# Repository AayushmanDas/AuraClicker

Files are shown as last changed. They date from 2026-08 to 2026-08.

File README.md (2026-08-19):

# ⚡ AuraClicker

A compact, battery-powered custom macro-pad and wireless input controller powered by the **ESP32-C3** RISC-V microcontroller. 

Designed natively in **KiCad** with end-to-end Design for Manufacturing (DFM) verification, ready for turnkey fabrication and assembly via JLCPCB SMT services.

---

## 📸 Media & Previews

| 3D PCB Preview | JLCPCB DFM Placement |
| :---: | :---: |
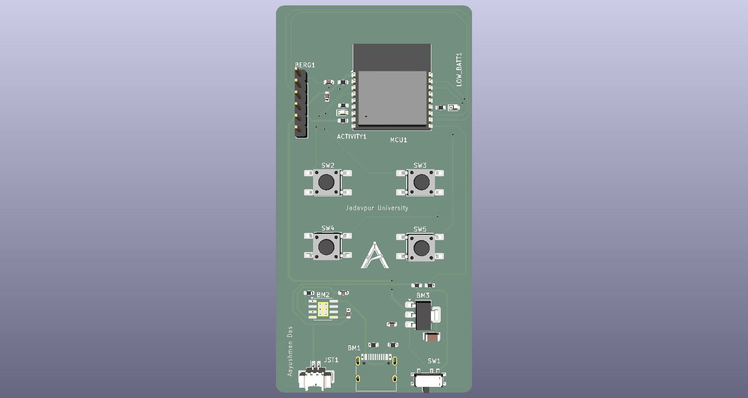
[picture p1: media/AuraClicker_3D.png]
3D Render
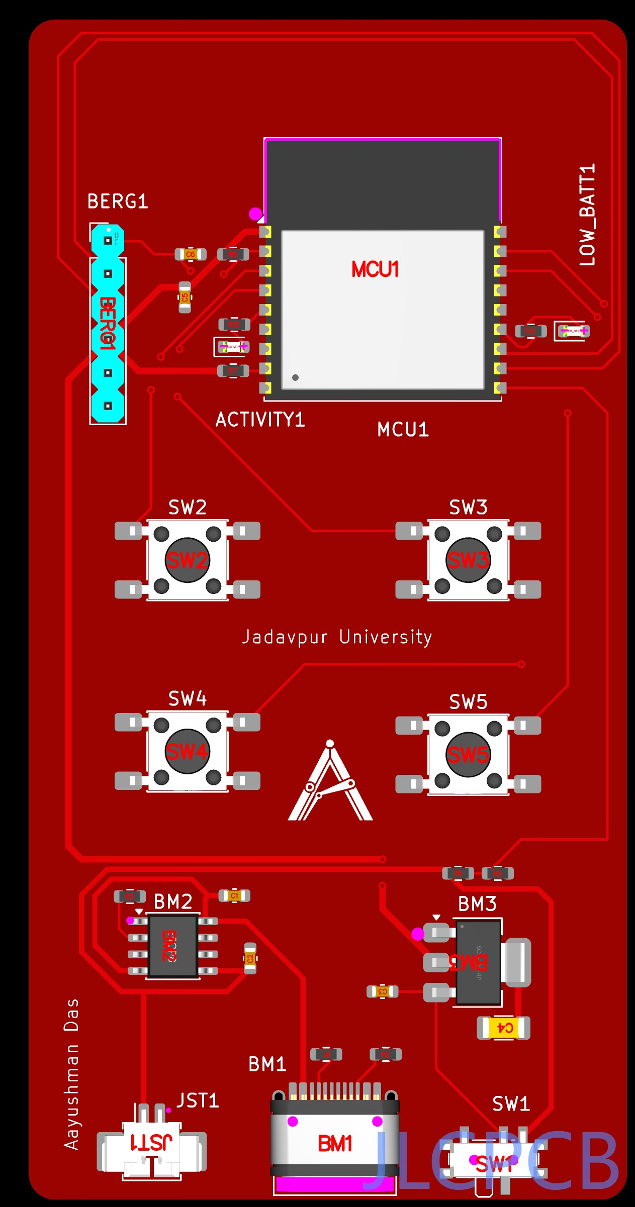
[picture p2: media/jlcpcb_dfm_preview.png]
DFM Preview
|  |  |

---

## ✨ Key Features

* **MCU Core:** ESP32-C3 RISC-V SoC (2.4 GHz Wi-Fi & Bluetooth 5 LE).
* **Power & Battery Management:**
  * Dedicated **TP4056** Li-Po linear charging IC over USB-C.
  * **AMS1117-3.3** high-current LDO for clean 3.3V power distribution.
  * 2-Pin **Molex PicoBlade (1.25mm)** battery connector. Recommended to be used with 3.7-4.2V 500mAh LiPo battery.
  * Hardware SPDT power slide switch (`SW1`).
* **Inputs & Peripherals:**
  * 4x Low-profile tactile click buttons (`SW2` – `SW5`) arranged for ergonomic thumb/finger reach.
  * Status LEDs for battery activity and low-power telemetry.
* **Programming & Debugging:**
  * Standard 1x6 (2.54mm) FTDI / UART header (`BERG1`) for serial programming and debug monitoring.

---

## 🗂️ Repository Structure

```text
AuraClicker/
├── kicad/                        # Raw KiCad project and PCB design files
│   ├── AuraClicker.kicad_pro
│   ├── AuraClicker.kicad_sch
│   ├── AuraClicker.kicad_pcb
│   ├── fp-lib-table
│   └── Team_Antarez_Logo.kicad_mod
│
├── production/                   # Fabrication-ready packages & CAD files
│   ├── AuraClicker_Fabrication.zip   # Gerber package ready for JLCPCB/PCBWay
│   ├── AuraClicker_BOM.xlsx          # Bill of Materials with LCSC part numbers
│   ├── AuraClicker_Placement.xlsx    # Pick & Place / Centroid coordinate file (.pos)
│   ├── AuraClicker_schem.pdf         # Printable PDF schematic
│   └── AuraClicker_Model.step        # Centered-origin 3D CAD STEP model
│
├── media/                        # Renders, schematics, and DFM validation captures
├── LICENSE
└── README.md
```

---

## 📌 Hardware Pin Mapping

| Peripheral | Reference | Net / Function | Active State |
| :--- | :--- | :--- | :--- |
| **Button 1** | `SW2` | Tactile Input | Active Low (Pull-up) |
| **Button 2** | `SW3` | Tactile Input | Active Low (Pull-up) |
| **Button 3** | `SW4` | Tactile Input | Active Low (Pull-up) |
| **Button 4** | `SW5` | Tactile Input | Active Low (Pull-up) |
| **Activity LED** | `D1` / `ACTIVITY1` | System Telemetry | Active High |
| **Low Batt LED** | `D2` / `LOW_BATT1` | Battery Warning | Active High |
| **Power Switch** | `SW1` | VBAT / VBUS Select | Hardware Cutoff |
| **UART Port** | `BERG1` | TX / RX / GND / 3V3 / DTR / RTS | 3.3V TTL Level |

---

## ⚠️ DFM Review & Assembly Notes (JLCPCB PCBA)

When placing a PCBA order via JLCPCB, verify the following manual adjustments during the **DFM Placement Review** step:

1. **`BERG1` (1x6 2.54mm Pin Header):**
   * *Rotation / Offset:* Rotate 90° and verify the 6 pins align over the through-hole pattern.
   * *Note:* If using **Economic PCBA**, through-hole components are not populated by default. Hand-solder this header manually upon delivery.
2. **`BM1` (USB-C 16-Pin Receptacle):**
   * *Placement:* Shift the component forward/inward along the Y-axis so the SMT signal pins land centered on the pads and the mechanical shield legs seat cleanly in their plated slots.
3. **`JST1` (Molex PicoBlade 1.25mm Header):**
   * *Placement:* Shift the component slightly inward (away from the outer PCB edge) along the Y-axis until the rear signal leads and side mechanical retention tabs center on their respective footprint pads.

---

## 🛠️ Fabrication & Ordering Quickstart

1. **Bare PCB Only:** Upload `production/Gerbers_AuraClicker.zip` to JLCPCB (FR-4, 1.6mm thickness, standard 2-layer).
2. **SMT Assembly:**
   * Enable **SMT Assembly**.
   * Upload `production/BOM_AuraClicker.csv` for the component list.
   * Upload `production/CPL_AuraClicker.csv` for pick-and-place centroid positions.
   * Product Category Recommendation: `Reserch\Education\DIY\Entertainment -> DIY Hobby Circuit Board` (*HS Code: 902300*).

---

## 📜 License & Trademark Notice

* **Hardware & Schematics:** Distributed under the **MIT License**. Feel free to modify, build, and redistribute the board.
* **Branding & Logos:** The **Team Antarez** insignia, logo graphics, and name are proprietary trademarks of Team Antarez. All rights reserved. You are free to manufacture and modify the hardware, but please remove proprietary team insignias from derivative or commercial releases.

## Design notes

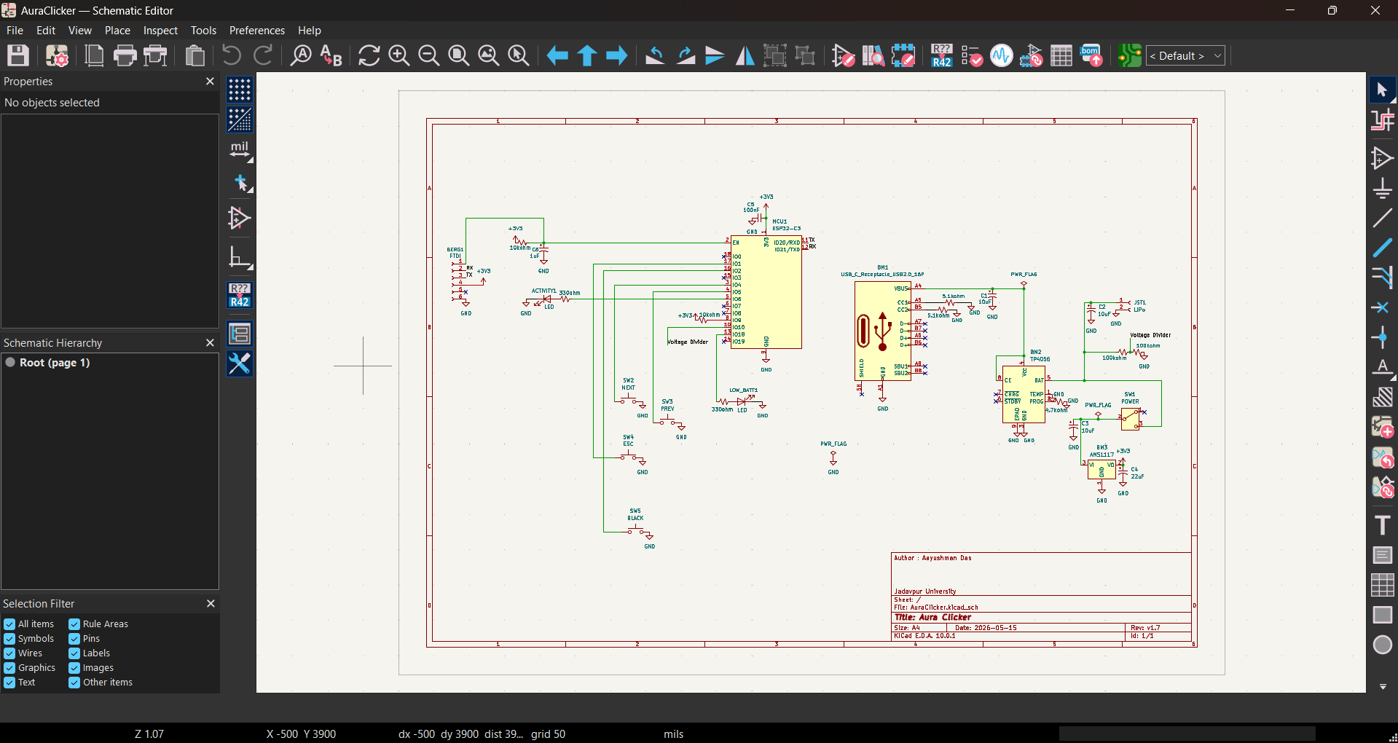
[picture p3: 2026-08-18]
media/schematic_preview.png

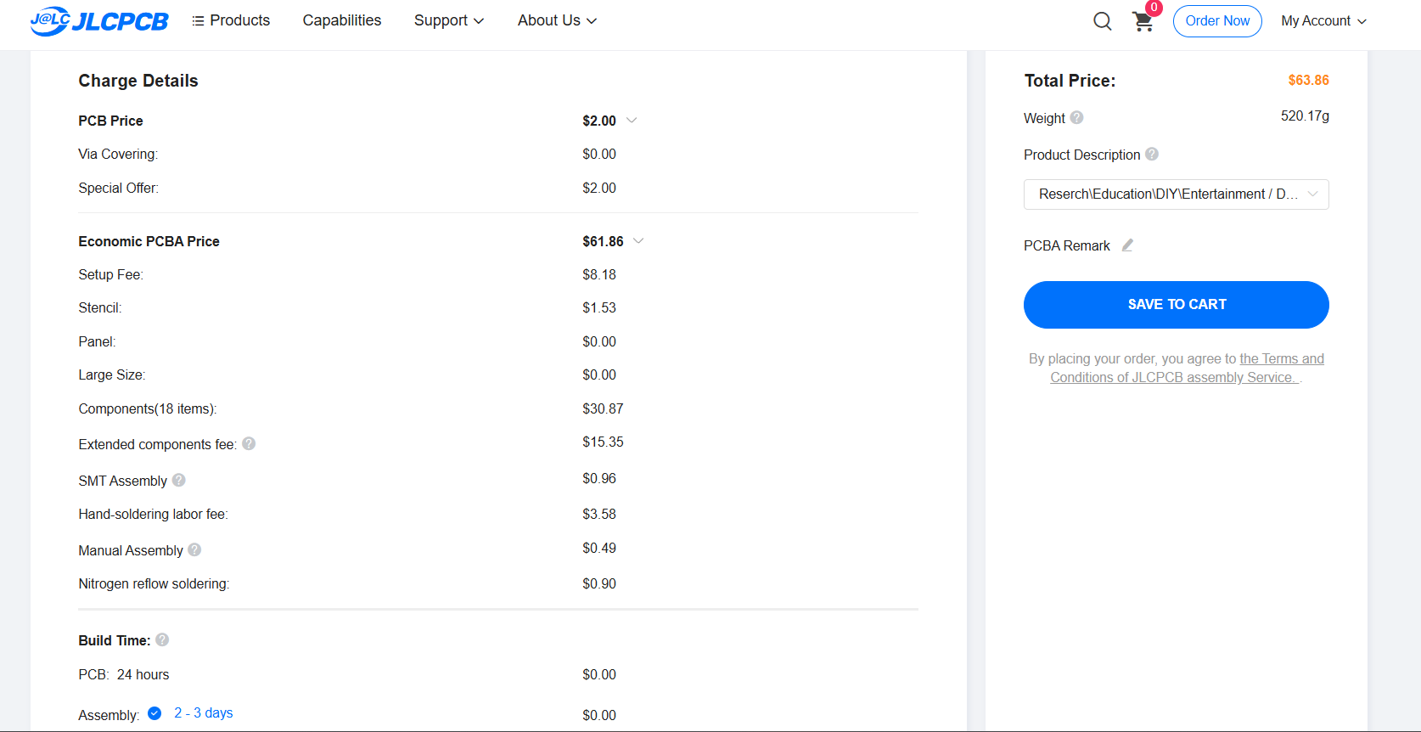
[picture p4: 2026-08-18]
media/price_breakdown.png

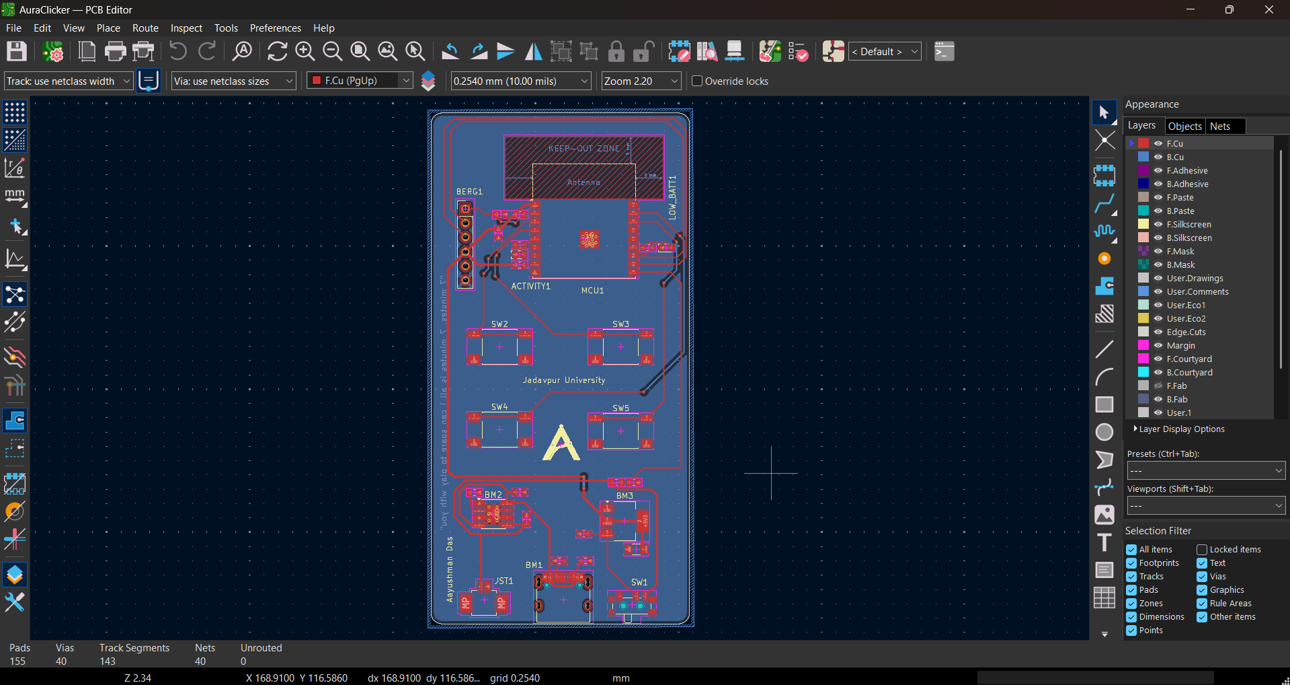
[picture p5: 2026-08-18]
media/pcb_preview.png

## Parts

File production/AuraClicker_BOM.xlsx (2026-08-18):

Serial Number | Manufacturing Part Number (MPN) | LCSC Part # | Designator | Quantity | Value | Footprint | Top/Bottom | Points (No. of Pins) | Comments
1 | KT-0603R | C2286 | ACTIVITY1,LOW_BATT1 | 2 | LED | LED_SMD:LED_0603_1608Metric | Top | 2
2 | PH2.54-06PB2G-H25 | C42431807 | BERG1 | 1 | FTDI | Connector_PinHeader_2.54mm:PinHeader_1x06_P2.54mm_Vertical | Top | 6
3 | HX USB3.1TYPE-C-16P FS | C41427498 | BM1 | 1 | USB_C_Receptacle_USB2.0_16P | Connector_USB:USB_C_Receptacle_HRO_TYPE-C-31-M-12 | Top | 16
4 | TP4056-42-ESOP8 | C16581 | BM2 | 1 | TP4056 | Package_SO:SOIC-8-1EP_3.9x4.9mm_P1.27mm_EP2.41x3.3mm_ThermalVias | Top | 9
5 | AMS1117-3.3 | C6186 | BM3 | 1 | AMS1117 | Package_TO_SOT_SMD:SOT-223-3_TabPin2 | Top | 4
6 | CL10A106KP8NNNC | C19702 | C1,C2,C3 | 3 | 10uF | Capacitor_SMD:C_0603_1608Metric | Top | 2
7 | CL31A226KAHNNNE | C12891 | C4 | 1 | 22uF | Capacitor_SMD:C_1206_3216Metric | Top | 2
8 | CC0603KRX7R9BB104 | C14663 | C5 | 1 | 100nF | Capacitor_SMD:C_0603_1608Metric | Top | 2
9 | CL10A105KB8NNNC | C15849 | C6 | 1 | 1uF | Capacitor_SMD:C_0603_1608Metric | Top | 2
10 | 1.25T-2PSurface Mount, Right Angle | C22074 | JST1 | 1 | LiPo | Connector_JST:JST_PH_B2B-PH-K_1x02_P2.00mm_Vertical | Top | 2
11 | ESP32-C3-WROOM-02-N4 | C2934560 | MCU1 | 1 | ESP32-C3 | RF_Module:ESP32-C3-WROOM-02 | Top | 19
12 | 0603WAF5101T5E | C23186 | R1,R2 | 2 | 5.1kohm | Resistor_SMD:R_0603_1608Metric | Top | 2
13 | 0603WAF4701T5E | C23162 | R3 | 1 | 4.7kohm | Resistor_SMD:R_0603_1608Metric | Top | 2
14 | 0603WAF1002T5E | C25804 | R6,R7 | 2 | 10kohm | Resistor_SMD:R_0603_1608Metric | Top | 2
15 | 0603WAF1003T5E | C25803 | R8,R9 | 2 | 100kohm | Resistor_SMD:R_0603_1608Metric | Top | 2
16 | 0603WAF3300T5E | C23138 | R10,R12 | 2 | 330ohm | Resistor_SMD:R_0603_1608Metric | Top | 2
17 | PCM12SMTR | C221841 | SW1 | 1 | POWER | Button_Switch_SMD:SW_SPDT_PCM12 | Top | 3
18 | SH-6X6X5H-TP | C42416254 | SW2 | 1 | NEXT | Button_Switch_SMD:SW_Push_1P1T_NO_E-Switch_TL3301NxxxxxG | Top | 4
19 | SH-6X6X5H-TP | C42416254 | SW3 | 1 | PREV | Button_Switch_SMD:SW_Push_1P1T_NO_E-Switch_TL3301NxxxxxG | Top | 4
20 | SH-6X6X5H-TP | C42416254 | SW4 | 1 | ESC | Button_Switch_SMD:SW_Push_1P1T_NO_E-Switch_TL3301NxxxxxG | Top | 4
21 | SH-6X6X5H-TP | C42416254 | SW5 | 1 | BLACK | Button_Switch_SMD:SW_Push_1P1T_NO_E-Switch_TL3301NxxxxxG | Top | 4

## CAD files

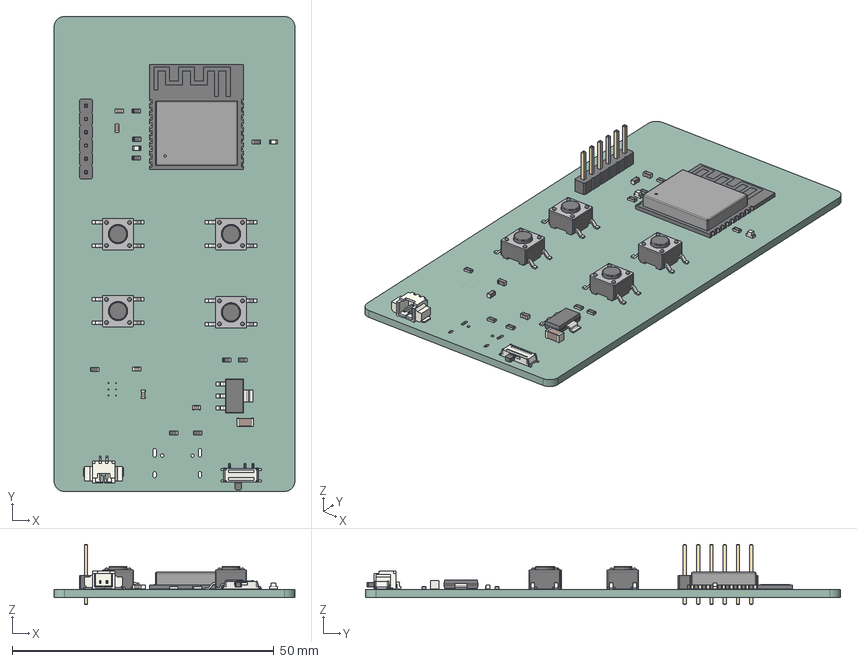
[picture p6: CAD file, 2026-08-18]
production/AuraClicker_Model.step
46.0 x 90.7 x 11.5 mm
R_0603_1608Metric x 9
SW_Push_1P1T_NO_E-Switch_TL3301NxxxxxG x 4
C_0603_1608Metric x 5
C_1206_3216Metric
LED_0603_1608Metric x 2
PinHeader_1x06_P2.54mm_Vertical
SOT-223
Molex_PicoBlade_53261-0271_1x02-1MP_P1.25mm_Horizontal
SW_SPDT_PCM12
ESP32-C3-WROOM-02
AuraClicker_PCB

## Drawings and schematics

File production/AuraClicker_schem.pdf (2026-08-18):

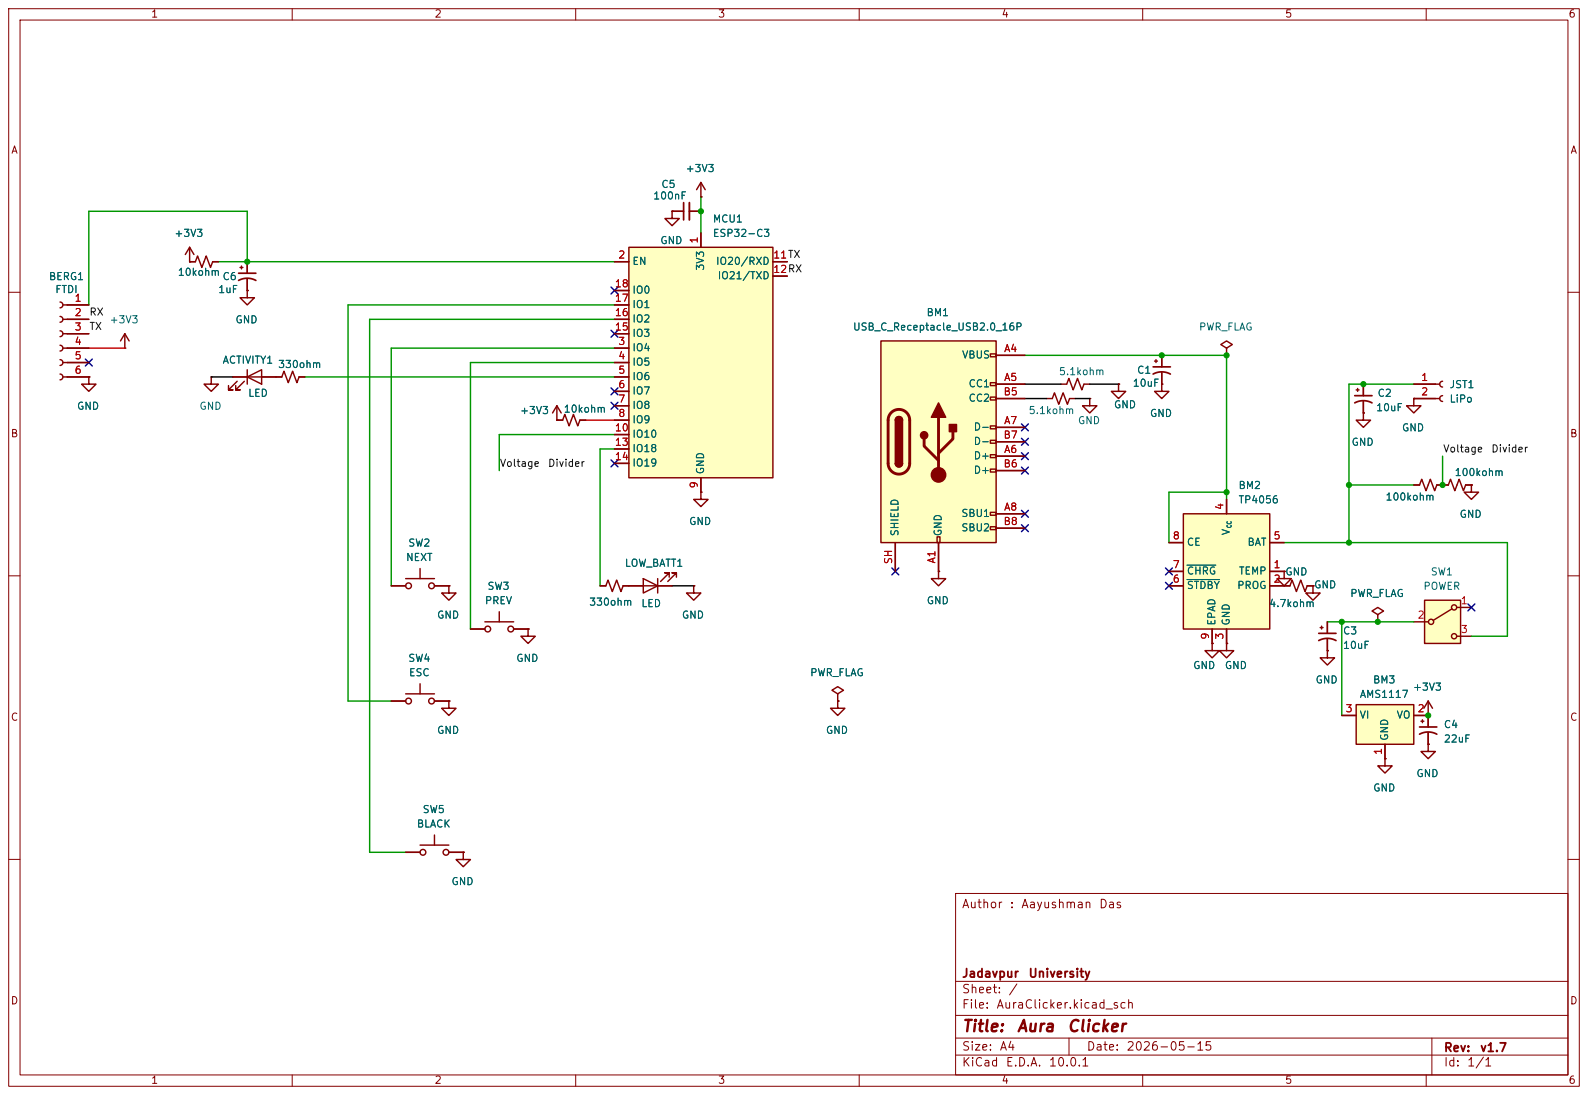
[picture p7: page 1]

Size: A4 | Rev: v1.7
KiCad E.D.A. 10.0.1 | Id: 1/1

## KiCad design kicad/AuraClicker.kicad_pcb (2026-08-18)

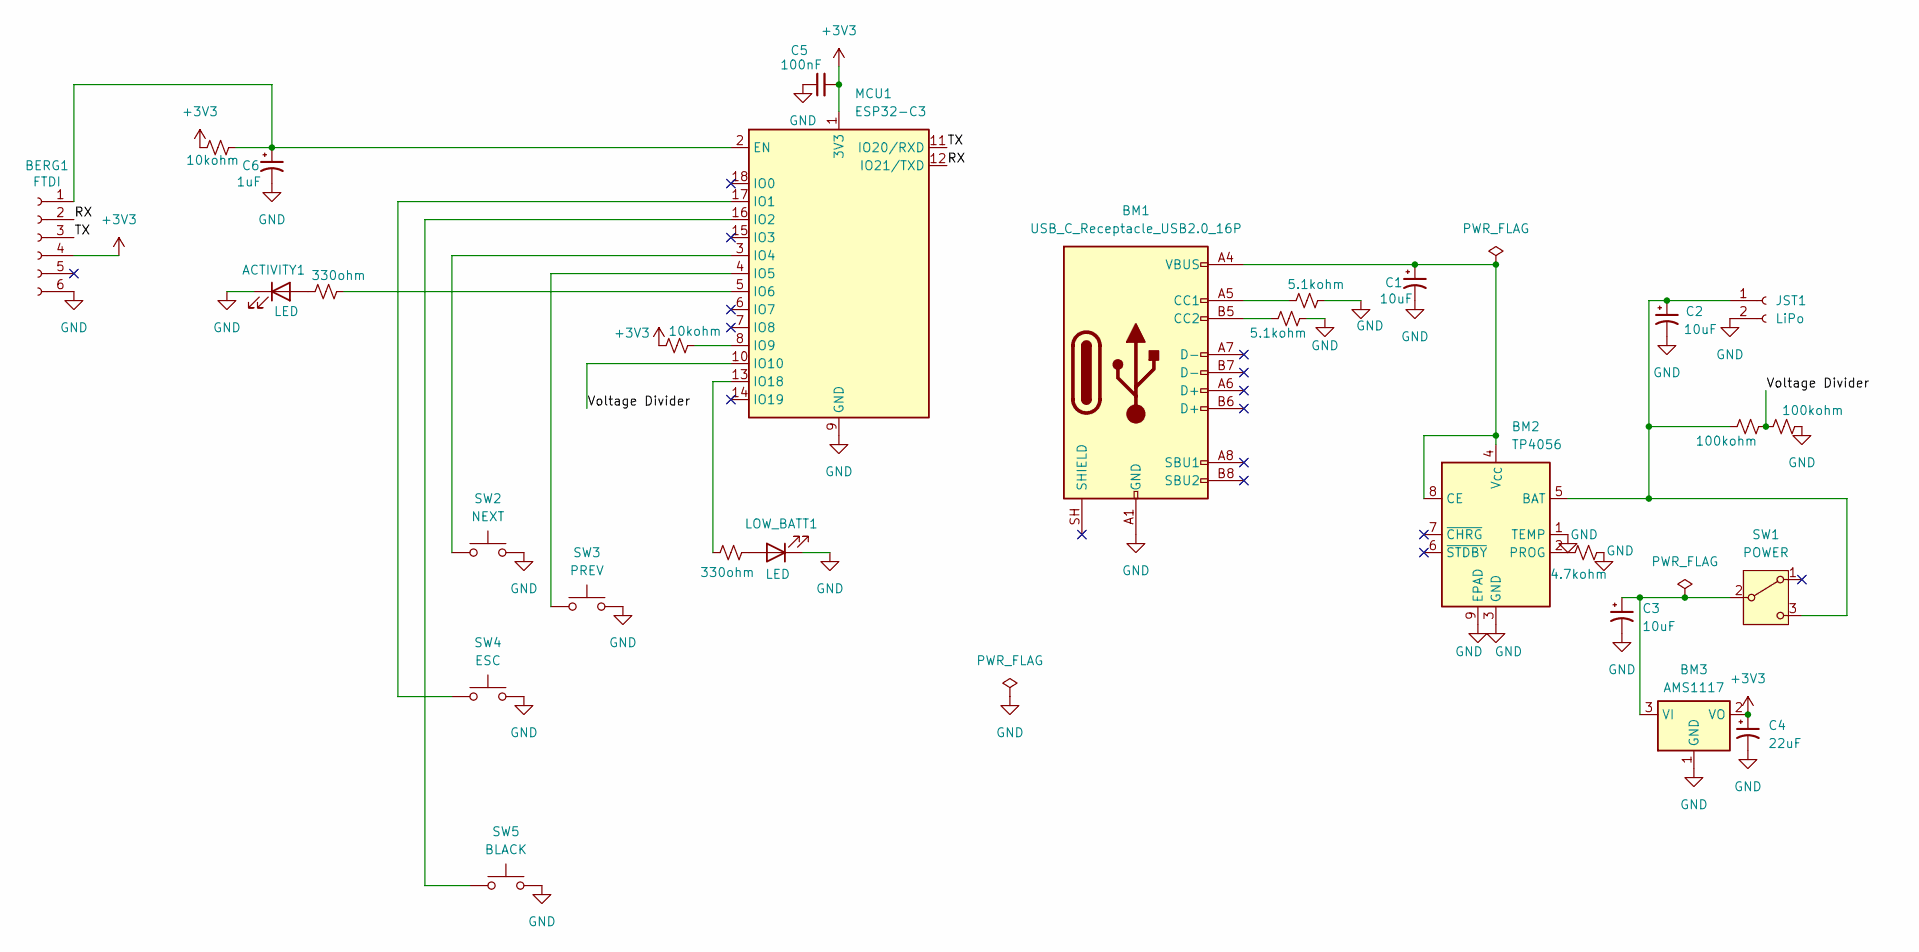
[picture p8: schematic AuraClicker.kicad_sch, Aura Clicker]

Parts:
ACTIVITY1: LED; LED_0603_1608Metric; MPN YLED0603G; LCSC Part Number C19273151
BERG1: FTDI; PinHeader_1x06_P2.54mm_Vertical; MPN PH2.54-06PB2G-H25; LCSC Part Number C42431807
BM1: USB_C_Receptacle_USB2.0_16P; USB_C_Receptacle_HRO_TYPE-C-31-M-12; MPN HX USB3.1TYPE-C-16P FS; LCSC Part Number C41427498
BM2: TP4056; SOIC-8-1EP_3.9x4.9mm_P1.27mm_EP2.41x3.3mm_ThermalVias; MPN TP4056; LCSC Part Number C382139
BM3: AMS1117; SOT-223-3_TabPin2; MPN AMS1117-3.3; LCSC Part Number C6186
C1, C2, C3: 10uF; C_0603_1608Metric; MPN TMCJ0J106MTRF; LCSC Part Number C1953982
C4: 22uF; C_1206_3216Metric; MPN TAJA226M016RNJ; LCSC Part Number C6328904
C5: 100nF; C_0603_1608Metric; MPN CC0603KRX7R9BB104; LCSC Part Number C14663
C6: 1uF; C_0603_1608Metric; MPN TACL105K016XTA; LCSC Part Number C1952789
JST1: LiPo; Molex_PicoBlade_53261-0271_1x02-1MP_P1.25mm_Horizontal; MPN S2B-PH-K(LF)(SN); LCSC Part Number C265016
LOW_BATT1: LED; LED_0603_1608Metric; MPN YLED0603G; LCSC Part Number C19273151
MCU1: ESP32-C3; ESP32-C3-WROOM-02; MPN ESP32-C3-WROOM-02-N4; LCSC Part Number C2934560
R1, R2: 5.1kohm; R_0603_1608Metric; MPN FRC0603F5101TS; LCSC Part Number C2907044
R3: 4.7kohm; R_0603_1608Metric; MPN RC0603FR-074K7L; LCSC Part Number C99782
R6, R7: 10kohm; R_0603_1608Metric; MPN RC0603FR-0710KL; LCSC Part Number C98220
R8, R9: 100kohm; R_0603_1608Metric; MPN RC0603FR-07100KL; LCSC Part Number C14675
R10, R12: 330ohm; R_0603_1608Metric; MPN RC0603FR-07330RL; LCSC Part Number C105881
SW1: POWER; SW_SPDT_PCM12; MPN MST-12D18G4 SPDT Slide Switch; LCSC Part Number C49023767
SW2: NEXT; SW_Push_1P1T_NO_E-Switch_TL3301NxxxxxG; MPN SH-6X6X5H-TP; LCSC Part Number C42416254
SW3: PREV; SW_Push_1P1T_NO_E-Switch_TL3301NxxxxxG; MPN SH-6X6X5H-TP; LCSC Part Number C42416254
SW4: ESC; SW_Push_1P1T_NO_E-Switch_TL3301NxxxxxG; MPN SH-6X6X5H-TP; LCSC Part Number C42416254
SW5: BLACK; SW_Push_1P1T_NO_E-Switch_TL3301NxxxxxG; MPN SH-6X6X5H-TP; LCSC Part Number C42416254

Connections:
+3V3: BERG1.4, BM3.2 (VO), C4.1, C5.2, MCU1.1 (3V3), R6.1, R7.1
/RX: BERG1.2, MCU1.12 (IO21/TXD)
/TX: BERG1.3, MCU1.11 (IO20/RXD)
/Voltage Divider: MCU1.10 (IO10), R8.2, R9.1
GND: ACTIVITY1.1 (K), BERG1.6, BM1.A1 (GND), BM1.A12 (GND), BM1.B1 (GND), BM1.B12 (GND), BM2.1 (TEMP), BM2.3 (GND), BM2.9 (EPAD), BM3.1 (GND), C1.2, C2.2, C3.2, C4.2, C5.1, C6.2, JST1.2, LOW_BATT1.1 (K), MCU1.9 (GND), MCU1.19 (GND), R1.2, R2.2, R3.2, R9.2, SW2.2, SW3.2, SW4.2, SW5.2
unnamed: ACTIVITY1.2 (A), R10.1
unnamed: BERG1.1, C6.1, MCU1.2 (EN), R6.2
unnamed: BM1.A5 (CC1), R1.1
unnamed: BM1.B5 (CC2), R2.1
unnamed: BM2.5 (BAT), C2.1, JST1.1, R8.1, SW1.3 (C)
unnamed: BM1.A4 (VBUS), BM1.A9 (VBUS), BM1.B4 (VBUS), BM1.B9 (VBUS), BM2.4 (V_{CC}), BM2.8 (CE), C1.1
unnamed: BM2.2 (PROG), R3.1
unnamed: BM3.3 (VI), C3.1, SW1.2 (B)
unnamed: LOW_BATT1.2 (A), R12.1
unnamed: MCU1.17 (IO1), SW4.1
unnamed: MCU1.16 (IO2), SW5.1
unnamed: MCU1.3 (IO4), SW2.1
unnamed: MCU1.4 (IO5), SW3.1
unnamed: MCU1.5 (IO6), R10.2
unnamed: MCU1.8 (IO9), R7.2
unnamed: MCU1.13 (IO18), R12.2

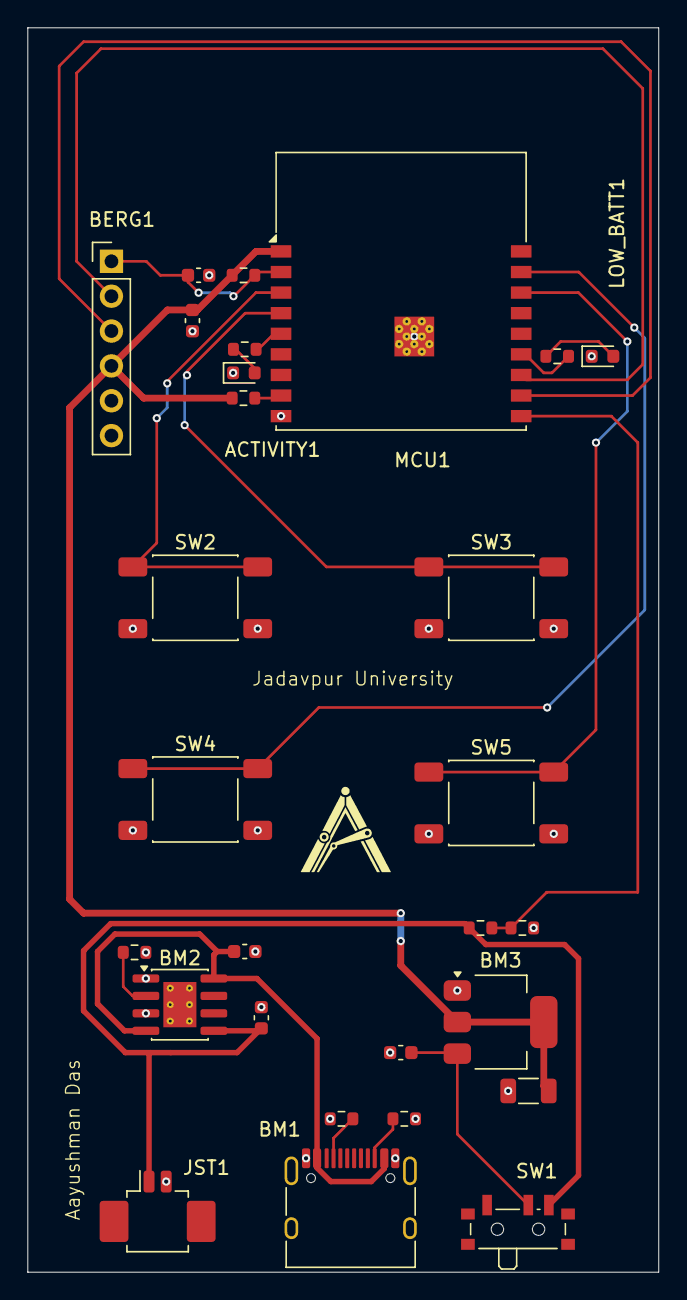
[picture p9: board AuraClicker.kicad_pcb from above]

Board: 2 copper layers, 46.0 x 90.7 mm, 28 parts (0 on the bottom side), 21 nets.

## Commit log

2026-08-18 Uploaded major kicad files
    [AuraClicker.kicad_pcb, AuraClicker.kicad_sch]
2026-08-18 Added the custom footprint
2026-08-18 Added Gerber+Drill files
2026-08-18 Added BOM and Placement files
    [AuraClicker_BOM.xlsx, AuraClicker_Placement.xlsx]
2026-08-18 Added model and schematic
    [AuraClicker_Model.step]
